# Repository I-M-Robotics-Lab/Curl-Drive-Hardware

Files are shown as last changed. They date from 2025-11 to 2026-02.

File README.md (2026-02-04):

# Curl-Drive: BLDC Motor Controller

This repository contains the hardware PCB design, schematics, and production files of the brushless motor FOC controller **Curl-Drive** developed by I'M Robotics Lab. 

The firmware is still under development, but the hardware has been validated with no major issues. Full version is planned to be released in early January. 

We welcome contributions from anyone! To get involved or ask questions, join our Discord server. 

Discord: https://discord.com/invite/WJuUWsy6DJ

Firmware (pre-release): https://github.com/I-M-Robotics-Lab/Curl-Drive-Firmware
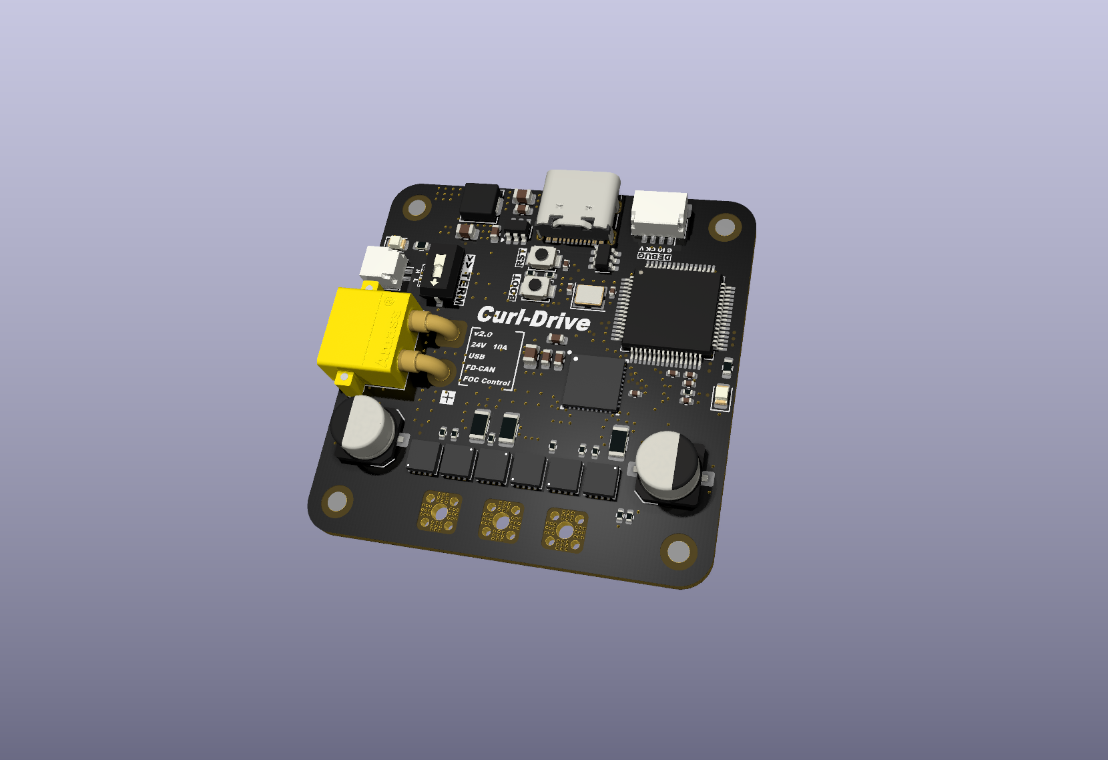
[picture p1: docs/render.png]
Rendered PCB


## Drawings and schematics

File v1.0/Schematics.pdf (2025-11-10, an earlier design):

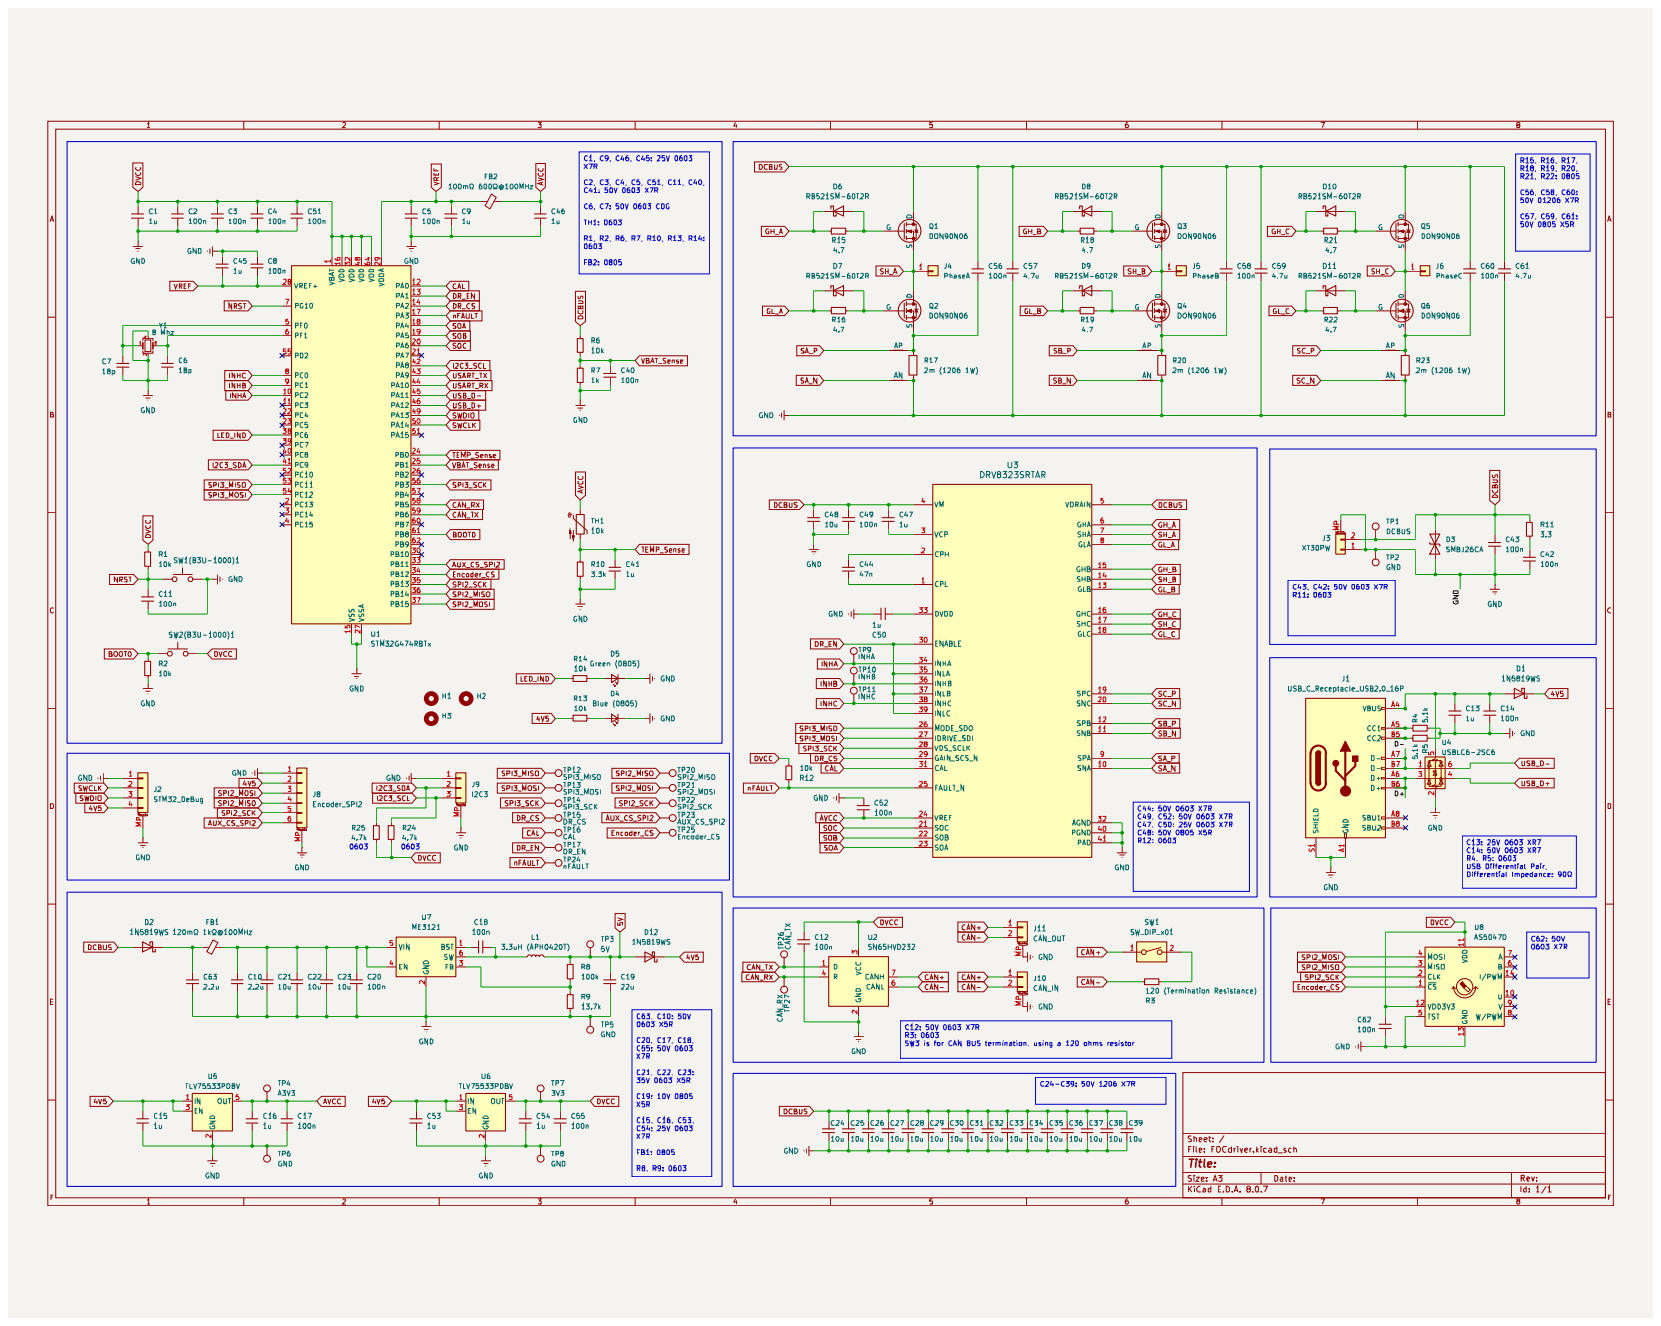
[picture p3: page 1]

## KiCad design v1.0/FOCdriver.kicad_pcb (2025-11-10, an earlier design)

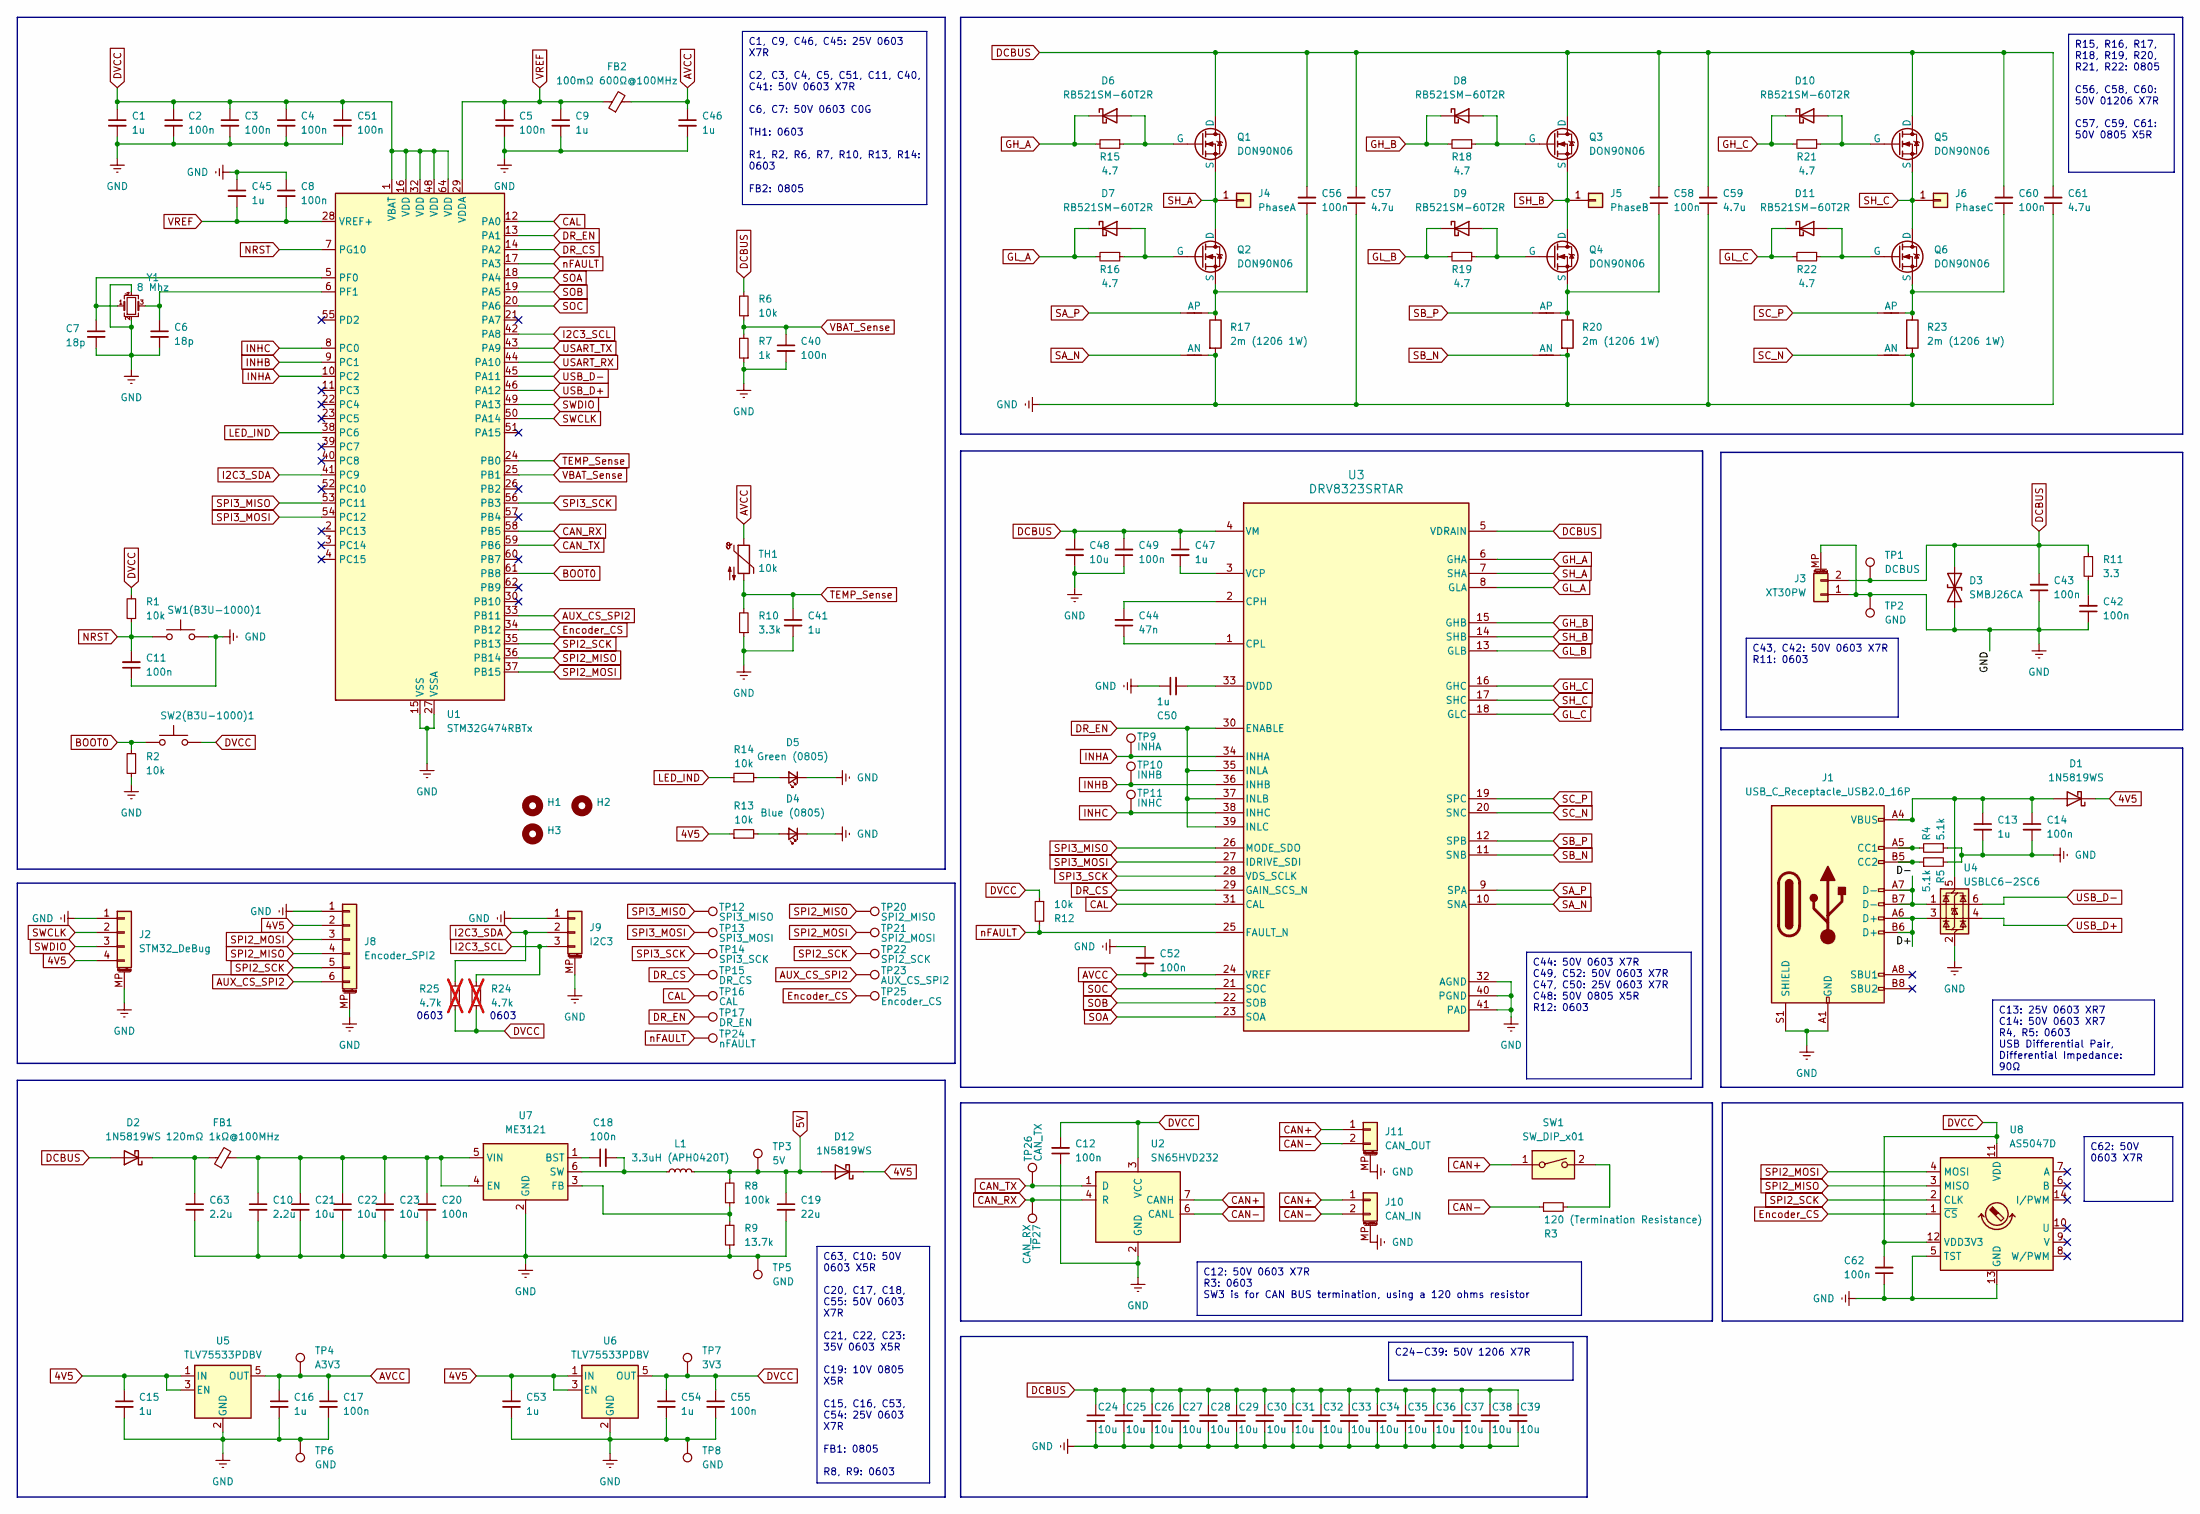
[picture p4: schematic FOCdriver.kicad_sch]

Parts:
C1, C9, C13, C15, C16, C41, C45, C46, C47, C50, C53, C54: 1u; C_0603_1608Metric
C2, C3, C4, C5, C8, C11, C12, C14, C17, C18, C20, C40, C42, C43, C49, C51, C52, C55, C62: 100n; C_0603_1608Metric
C6, C7: 18p; C_0603_1608Metric
C10, C63: 2.2u; C_0603_1608Metric
C19: 22u; C_0805_2012Metric
C21, C22, C23: 10u; C_0603_1608Metric
C24, C25, C26, C27, C28, C29, C30, C31, C32, C33, C34, C35, C36, C37, C38, C39: 10u; C_1206_3216Metric
C44: 47n; C_0603_1608Metric
C48: 10u; C_0805_2012Metric
C56, C58, C60: 100n; C_1206_3216Metric
C57, C59, C61: 4.7u; C_0805_2012Metric
D1, D2, D12: 1N5819WS; D_SOD-323
D3: SMBJ26CA; D_SMB
D4: Blue (0805); LED_0805_2012Metric
D5: Green (0805); LED_0805_2012Metric
D6, D7, D8, D9, D10, D11: RB521SM-60T2R; D_SOD-523
FB1: 120mΩ 1kΩ@100MHz; R_0805_2012Metric
FB2: 100mΩ 600Ω@100MHz; R_0805_2012Metric
H1, H2, H3: MountingHole_2.2mm_M2_DIN965_Pad
J1: USB_C_Receptacle_USB2.0_16P; USB_C_Receptacle_G-Switch_GT-USB-7010ASV
J2: STM32_DeBug; JST_SH_SM04B-SRSS-TB_1x04-1MP_P1.00mm_Horizontal
J3: XT30PW; AMASS_XT30PW-M_1x02_P2.50mm_Horizontal
J4: PhaseA; 4.5x4.5_pad
J5: PhaseB; 4.5x4.5_pad
J6: PhaseC; 4.5x4.5_pad
J8: Encoder_SPI2; JST_SH_SM06B-SRSS-TB_1x06-1MP_P1.00mm_Horizontal
J9: I2C3; JST_SH_SM03B-SRSS-TB_1x03-1MP_P1.00mm_Horizontal
J10: CAN_IN; JST_SH_SM02B-SRSS-TB_1x02-1MP_P1.00mm_Horizontal
J11: CAN_OUT; JST_SH_SM02B-SRSS-TB_1x02-1MP_P1.00mm_Horizontal
L1: 3.3uH (APH0420T); L_APV_APH0420
NT1, NT3, NT5: AP; NetTie-2
NT2, NT4, NT6: AN; NetTie-2
Q1, Q2, Q3, Q4, Q5, Q6: DON90N06; DFN-8-1EP_6x5mm_MOSFET
R1, R2, R6, R12, R13, R14: 10k; R_0603_1608Metric
R3: 120 (Termination Resistance); R_0603_1608Metric
R4, R5: 5.1k; R_0603_1608Metric
R7: 1k; R_0603_1608Metric
R8: 100k; R_0603_1608Metric
R9: 13.7k; R_0603_1608Metric
R10: 3.3k; R_0603_1608Metric
R11: 3.3; R_0603_1608Metric
R15, R16, R18, R19, R21, R22: 4.7; R_0603_1608Metric
R17, R20, R23: 2m (1206 1W); R_1206_3216Metric
R24, R25: 4.7k; R_0603_1608Metric; not fitted
SW1: SW_DIP_x01; SW_SPST_DSHP-01-TJ-GER
SW1(B3U-1000)1, SW2(B3U-1000)1: SW_Push; SW_SPST_B3U-1000P
TH1: 10k; R_0603_1608Metric
TP1: DCBUS; TestPoint_Pad_D0.4mm
TP2, TP5, TP6, TP8: GND; TestPoint_Pad_D0.4mm
TP3: 5V; TestPoint_Pad_D0.4mm
TP4: A3V3; TestPoint_Pad_D0.4mm
TP7: 3V3; TestPoint_Pad_D0.4mm
TP9: INHA; TestPoint_Pad_D0.4mm
TP10: INHB; TestPoint_Pad_D0.4mm
TP11: INHC; TestPoint_Pad_D0.4mm
TP12: SPI3_MISO; TestPoint_Pad_D0.4mm
TP13: SPI3_MOSI; TestPoint_Pad_D0.4mm
TP14: SPI3_SCK; TestPoint_Pad_D0.4mm
TP15: DR_CS; TestPoint_Pad_D0.4mm
TP16: CAL; TestPoint_Pad_D0.4mm
TP17: DR_EN; TestPoint_Pad_D0.4mm
TP20: SPI2_MISO; TestPoint_Pad_D0.4mm
TP21: SPI2_MOSI; TestPoint_Pad_D0.4mm
TP22: SPI2_SCK; TestPoint_Pad_D0.4mm
TP23: AUX_CS_SPI2; TestPoint_Pad_D0.4mm
TP24: nFAULT; TestPoint_Pad_D0.4mm
TP25: Encoder_CS; TestPoint_Pad_D0.4mm
TP26: CAN_TX; TestPoint_Pad_D0.4mm
TP27: CAN_RX; TestPoint_Pad_D0.4mm
U1: STM32G474RBTx; LQFP-64_10x10mm_P0.5mm
U2: SN65HVD232; SOIC-8_3.9x4.9mm_P1.27mm
U3: DRV8323SRTAR; DRV8323
U4: USBLC6-2SC6; SOT-23-6
U5, U6: TLV75533PDBV; SOT-23-5
U7: ME3121; SOT-23-6
U8: AS5047D; TSSOP-14_4.4x5mm_P0.65mm
Y1: 8 Mhz; Crystal_SMD_3225-4Pin_3.2x2.5mm

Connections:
4V5: C15.1, C53.1, D1.1 (K), D12.1 (K), J2.4, J8.2, R13.1, U5.1 (IN), U5.3 (EN), U6.1 (IN), U6.3 (EN)
5V: C19.1, D12.2 (A), L1.2, R8.2, TP3.1
/D+: J1.A6 (D+), J1.B6 (D+), U4.3 (I/O2)
/D-: J1.A7 (D-), J1.B7 (D-), U4.1 (I/O1)
AUX_CS_SPI2: J8.6, TP23.1, U1.33 (PB11)
AVCC: C16.1, C17.1, C46.1, C52.1, FB2.2, TH1.1, TP4.1, U3.24 (VREF), U5.5 (OUT)
BOOT0: R2.2, SW2(B3U-1000)1.1, U1.61 (PB8)
CAL: TP16.1, U1.12 (PA0), U3.31 (CAL)
CAN+: J10.1, J11.1, SW1.1, U2.7 (CANH)
CAN-: J10.2, J11.2, R3.1, U2.6 (CANL)
CAN_RX: TP27.1, U1.58 (PB5), U2.4 (R)
CAN_TX: TP26.1, U1.59 (PB6), U2.1 (D)
DCBUS: C24.1, C25.1, C26.1, C27.1, C28.1, C29.1, C30.1, C31.1, C32.1, C33.1, C34.1, C35.1, C36.1, C37.1, C38.1, C39.1, C43.2, C47.1, C48.1, C49.2, C56.2, C57.2, C58.2, C59.2, C60.2, C61.2, D2.2 (A), D3.2 (A2), J3.2, Q1.1 (D), Q3.1 (D), Q5.1 (D), R6.2, R11.2, TP1.1, U3.4 (VM), U3.5 (VDRAIN)
DR_CS: TP15.1, U1.14 (PA2), U3.29 (GAIN_SCS_N)
DR_EN: TP17.1, U1.13 (PA1), U3.30 (ENABLE), U3.35 (INLA), U3.37 (INLB), U3.39 (INLC)
DVCC: C1.1, C2.1, C3.1, C4.1, C12.2, C51.1, C54.1, C55.1, C62.2, R1.2, R12.1, R24.1, R25.1, SW2(B3U-1000)1.2, TP7.1, U1.1 (VBAT), U1.16 (VDD), U1.32 (VDD), U1.48 (VDD), U1.64 (VDD), U2.3 (VCC), U6.5 (OUT), U8.11 (VDD), U8.12 (VDD3V3)
Encoder_CS: TP25.1, U1.34 (PB12), U8.1 (~CS)
GH_A: D6.1 (K), R15.2, U3.6 (GHA)
GH_B: D8.1 (K), R18.2, U3.15 (GHB)
GH_C: D10.1 (K), R21.2, U3.16 (GHC)
GL_A: D7.1 (K), R16.2, U3.8 (GLA)
GL_B: D9.1 (K), R19.2, U3.13 (GLB)
GL_C: D11.1 (K), R22.2, U3.18 (GLC)
GND: C1.2, C2.2, C3.2, C4.2, C5.2, C6.2, C7.2, C8.1, C9.2, C10.2, C11.1, C12.1, C13.2, C14.2, C15.2, C16.2, C17.2, C19.2, C20.2, C21.2, C22.2, C23.2, C24.2, C25.2, C26.2, C27.2, C28.2, C29.2, C30.2, C31.2, C32.2, C33.2, C34.2, C35.2, C36.2, C37.2, C38.2, C39.2, C40.2, C41.2, C42.1, C43.1, C45.1, C46.2, C48.2, C49.1, C50.1, C51.2, C52.2, C53.2, C54.2, C55.2, C57.1, C59.1, C61.1, C62.1, C63.2, D3.1 (A1), D4.1 (K), D5.1 (K), H1.1, H2.1, H3.1, J1.A1 (GND), J1.A12 (GND), J1.B1 (GND), J1.B12 (GND), J1.S1 (SHIELD), J2.1, J2.MP (MountPin), J3.1, J3.MP (MountPin), J8.1, J8.MP (MountPin), J9.1, J9.MP (MountPin), J10.MP (MountPin), J11.MP (MountPin), NT2.2, NT4.2, NT6.2, R2.1, R4.1, R5.2, R7.1, R9.1, R10.1, R17.2, R20.2, R23.2, SW1(B3U-1000)1.2, TP2.1, TP5.1, TP6.1, TP8.1, U1.15 (VSS), U1.27 (VSSA), U1.31 (VSS), U1.47 (VSS), U1.63 (VSS), U2.2 (GND), U3.32 (AGND), U3.40 (PGND), U3.41 (PAD), U4.2 (GND), U5.2 (GND), U6.2 (GND), U7.2 (GND), U8.5 (TST), U8.13 (GND), Y1.2, Y1.4
I2C3_SCL: J9.3, R24.2, U1.42 (PA8)
I2C3_SDA: J9.2, R25.2, U1.41 (PC9)
INHA: TP9.1, U1.10 (PC2), U3.34 (INHA)
INHB: TP10.1, U1.9 (PC1), U3.36 (INHB)
INHC: TP11.1, U1.8 (PC0), U3.38 (INHC)
LED_IND: R14.1, U1.38 (PC6)
NRST: C11.2, R1.1, SW1(B3U-1000)1.1, U1.7 (PG10)
unnamed: C42.2, R11.1
unnamed: C13.1, C14.1, D1.2 (A), J1.A4 (VBUS), J1.A9 (VBUS), J1.B4 (VBUS), J1.B9 (VBUS), U4.5 (VBUS)
unnamed: C63.1, D2.1 (K), FB1.1
unnamed: D4.2 (A), R13.2
unnamed: D5.2 (A), R14.2
unnamed: D6.2 (A), Q1.2 (G), R15.1
unnamed: D7.2 (A), Q2.2 (G), R16.1
unnamed: D8.2 (A), Q3.2 (G), R18.1
unnamed: D9.2 (A), Q4.2 (G), R19.1
unnamed: D10.2 (A), Q5.2 (G), R21.1
unnamed: D11.2 (A), Q6.2 (G), R22.1
unnamed: J1.A5 (CC1), R4.2
unnamed: J1.B5 (CC2), R5.1
unnamed: C56.1, NT1.2, Q2.3 (S), R17.1
unnamed: C58.1, NT3.2, Q4.3 (S), R20.1
unnamed: C60.1, NT5.2, Q6.3 (S), R23.1
unnamed: R3.2, SW1.2
unnamed: C7.1, U1.5 (PF0), Y1.1
unnamed: C6.1, U1.6 (PF1), Y1.3
unnamed: C44.2, U3.2 (CPH)
unnamed: C44.1, U3.1 (CPL)
unnamed: C50.2, U3.33 (DVDD)
unnamed: C47.2, U3.3 (VCP)
unnamed: C18.1, U7.1 (BST)
unnamed: C10.1, C20.1, C21.1, C22.1, C23.1, FB1.2, U7.4 (EN), U7.5 (VIN)
unnamed: R8.1, R9.2, U7.3 (FB)
unnamed: C18.2, L1.1, U7.6 (SW)
SA_N: NT2.1, U3.10 (SNA)
SA_P: NT1.1, U3.9 (SPA)
SB_N: NT4.1, U3.11 (SNB)
SB_P: NT3.1, U3.12 (SPB)
SC_N: NT6.1, U3.20 (SNC)
SC_P: NT5.1, U3.19 (SPC)
SH_A: J4.1, Q1.3 (S), Q2.1 (D), U3.7 (SHA)
SH_B: J5.1, Q3.3 (S), Q4.1 (D), U3.14 (SHB)
SH_C: J6.1, Q5.3 (S), Q6.1 (D), U3.17 (SHC)
SOA: U1.18 (PA4), U3.23 (SOA)
SOB: U1.19 (PA5), U3.22 (SOB)
SOC: U1.20 (PA6), U3.21 (SOC)
SPI2_MISO: J8.4, TP20.1, U1.36 (PB14), U8.3 (MISO)
SPI2_MOSI: J8.3, TP21.1, U1.37 (PB15), U8.4 (MOSI)
SPI2_SCK: J8.5, TP22.1, U1.35 (PB13), U8.2 (CLK)
SPI3_MISO: TP12.1, U1.53 (PC11), U3.26 (MODE_SDO)
SPI3_MOSI: TP13.1, U1.54 (PC12), U3.27 (IDRIVE_SDI)
SPI3_SCK: TP14.1, U1.56 (PB3), U3.28 (VDS_SCLK)
SWCLK: J2.2, U1.50 (PA14)
SWDIO: J2.3, U1.49 (PA13)
TEMP_Sense: C41.1, R10.2, TH1.2, U1.24 (PB0)
USART_RX: U1.44 (PA10)
USART_TX: U1.43 (PA9)
USB_D+: U1.46 (PA12), U4.4 (I/O2)
USB_D-: U1.45 (PA11), U4.6 (I/O1)
VBAT_Sense: C40.1, R6.1, R7.2, U1.25 (PB1)
VREF: C5.1, C8.2, C9.1, C45.2, FB2.1, U1.28 (VREF+), U1.29 (VDDA)
nFAULT: R12.2, TP24.1, U1.17 (PA3), U3.25 (FAULT_N)

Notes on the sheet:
C63, C10: 50V 0603 X5R C20, C17, C18, C55: 50V 0603 X7R C21, C22, C23: 35V 0603 X5R C19: 10V 0805 X5R C15, C16, C53, C54: 25V 0603 X7R FB1: 0805 R8, R9: 0603
C62: 50V 0603 X7R
C13: 25V 0603 XR7 C14: 50V 0603 XR7 R4, R5: 0603 USB Differential Pair, Differential Impedance: 90Ω
R15, R16, R17, R18, R19, R20, R21, R22: 0805 C56, C58, C60: 50V 01206 X7R C57, C59, C61: 50V 0805 X5R
C43, C42: 50V 0603 X7R R11: 0603
C1, C9, C46, C45: 25V 0603 X7R C2, C3, C4, C5, C51, C11, C40, C41: 50V 0603 X7R C6, C7: 50V 0603 C0G TH1: 0603 R1, R2, R6, R7, R10, R13, R14: 0603 FB2: 0805
C24-C39: 50V 1206 X7R
C44: 50V 0603 X7R C49, C52: 50V 0603 X7R C47, C50: 25V 0603 X7R C48: 50V 0805 X5R R12: 0603
C12: 50V 0603 X7R R3: 0603 SW3 is for CAN BUS termination, using a 120 ohms resistor
0603

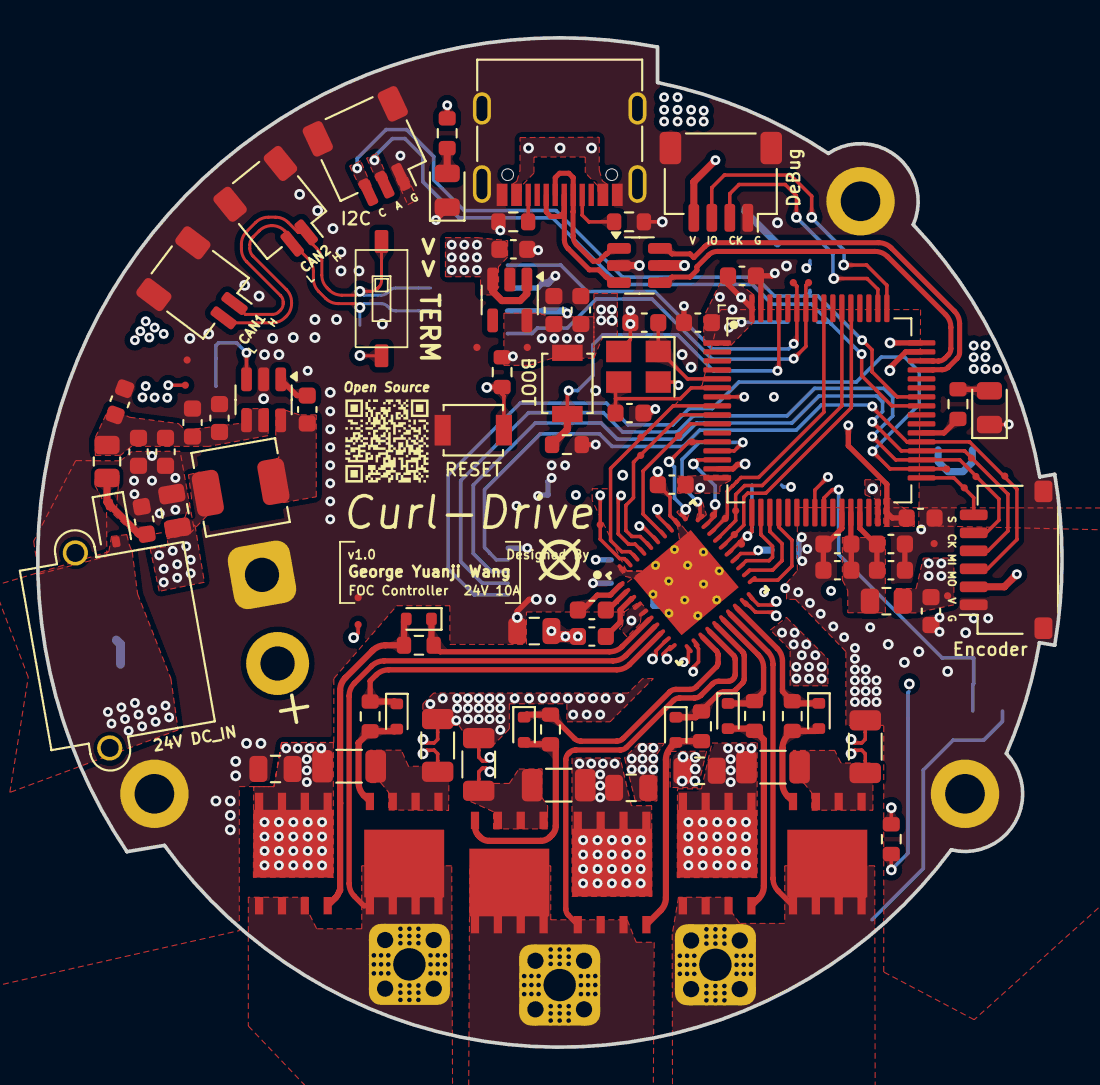
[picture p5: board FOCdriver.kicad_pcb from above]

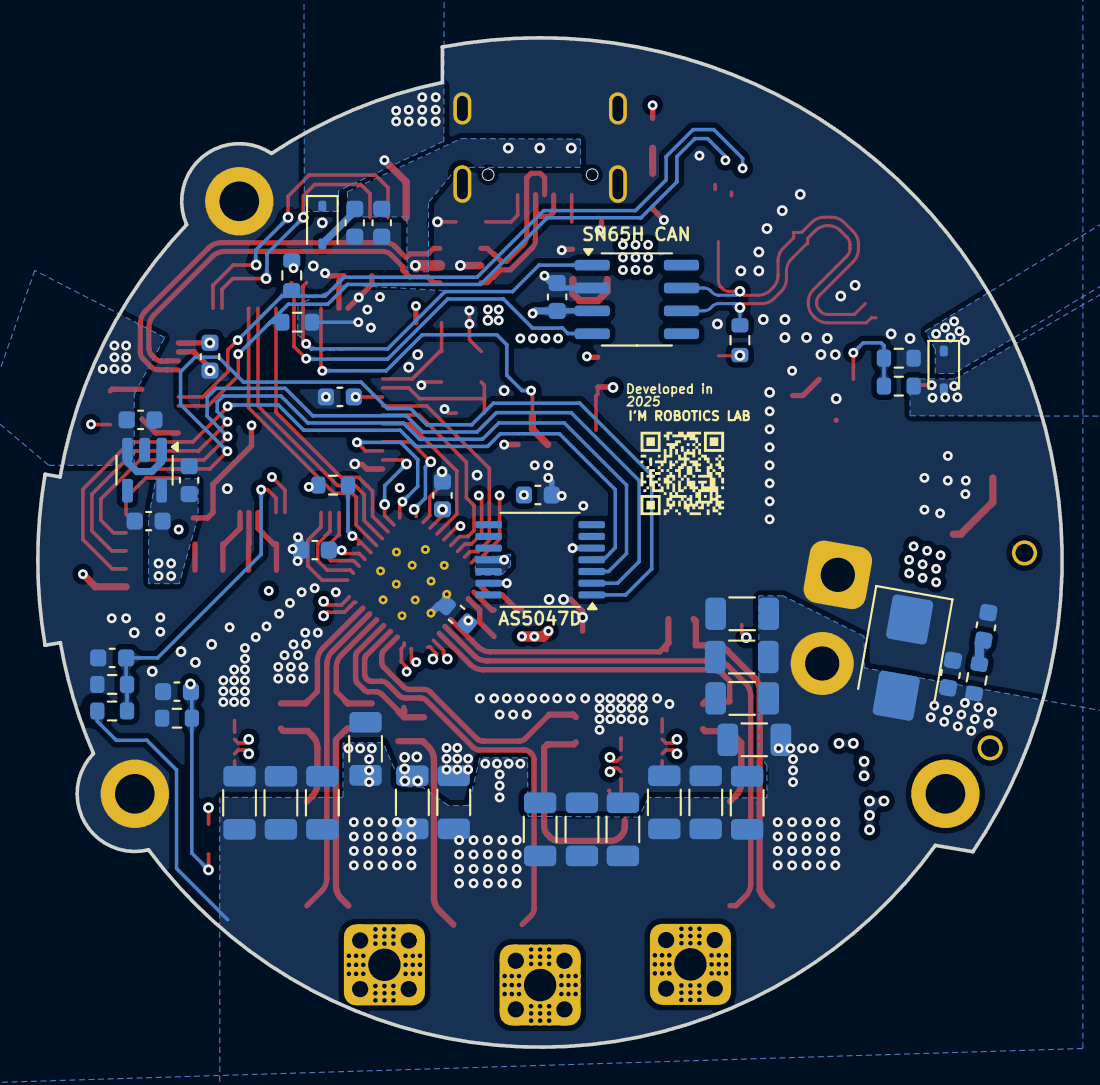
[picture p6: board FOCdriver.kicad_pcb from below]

Board: 4 copper layers, 56.9 x 56.1 mm, 166 parts (48 on the bottom side), 84 nets.
